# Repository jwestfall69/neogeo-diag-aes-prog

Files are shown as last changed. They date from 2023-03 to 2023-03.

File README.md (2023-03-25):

# neogeo-diag-aes-prog

## Overview
This is a custom NeoGeo AES Prog board that is used in conjunction with the [NeoGeo Diag Bios](https://github.com/jwestfall69/neogeo-diag-bios) that allows for testing the P ROM address and data buses between the motherboard and the cart slot.  Its meant to help trouble shoot getting a blue screen or if your game cart boots then crashes after a while (possible faulty P ROM bank switching).

It works by using an SRAM chip instead of a ROM for the program rom on the PROG board.  Doing this allows the diag bios to run tests on it similar to that of work ram to find issues.

Its not possible to test all lines related to the program rom, so there are 2 leds at the top of the board.  These 2 LEDs (ROMOE, PORTADDR) should be lit up when the P ROM Bus tests are running in the diag bios.

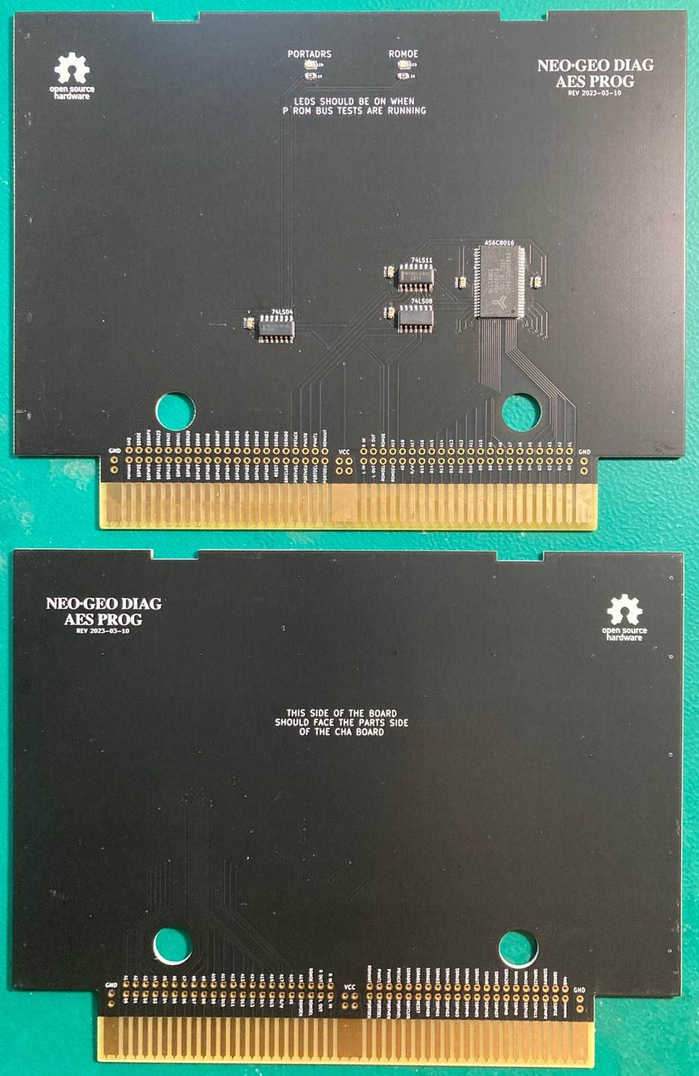
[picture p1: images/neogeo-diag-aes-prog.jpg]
neogeo-diag-aes-prog


## PCB Manufacturing
PCB should be 1.6mm thickness.  With these boards likely being inserted and removed numerous times its suggested you use ENIG surface finishing and gold fingers w/45 degree chamfering.

I've been using [jlcpcb](https://jlcpcb.com/) for PCB manufacturing.  Just watch out that by default they will add an order number to the silk screen unless you tell them not to.

## BOM
| Quantity | Description | Part Number | Digikey | Notes |
|:---:|:---|---|---|---|
| 1 | SRAM 8Mbit 44 pin TSOP II | AS6C8016-55ZIN | [1450-1041-ND](https://www.digikey.com/en/products/detail/alliance-memory-inc/AS6C8016-55ZIN/4234600) | |
| 1 | 74LS04 pin 14 SOIC | SN74LS04DR | [296-14875-2-ND](https://www.digikey.com/en/products/detail/texas-instruments/SN74LS04DR/562927) | |
| 1 | 74LS08 pin 14 SOIC | SN74LS08DR | [296-14879-2-ND](https://www.digikey.com/en/products/detail/texas-instruments/SN74LS08DR/562906) | |
| 1 | 74LS11 pin 14 SOIC | SN74LS11DR | [296-28984-2-ND](https://www.digikey.com/en/products/detail/texas-instruments/SN74LS11DR/1571760) | |
| 5 | 100nf / 0.1uf Ceramic Capacitor 0805 Size | CL21B104KBCNNNC | [1276-1003-2-ND](https://www.digikey.com/en/products/detail/samsung-electro-mechanics/CL21B104KBCNNNC/3886661) | Any 100nf 0805 is fine |
| 2 | 1K Ohm resistor 0805 Size | ERJ-6GEYJ102V | [P1.0KACT-ND](https://www.digikey.com/en/products/detail/panasonic-electronic-components/ERJ-6GEYJ102V/83014) | Any 1K 0805 resistor is fine |
| 2 | Green LED 0805 12mcd | LTST-C171GKT | [160-1423-2-ND](https://www.digikey.com/en/products/detail/liteon/LTST-C171GKT/386793) | Other 0805 size LEDs should be fine |

## Assembly
The SRAM has a really fine pin pitch, so take your time.  Other then that nothing special.

## Usage
The prog board should be used along with a valid CHA board.  Ideally you probably want a full diag cart where the CHA board has the M1 diag rom and this PROG board.  The cart should be inserted into the slot and then boot the board with the diag bios. Goto the main menu screen.

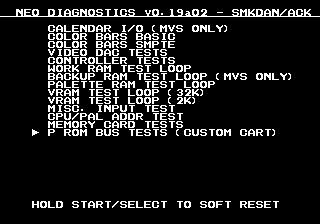
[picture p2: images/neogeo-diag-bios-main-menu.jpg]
main menu


Pick: ```P ROM BUS TESTS (CUSTOM CART)```

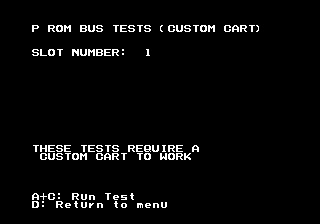
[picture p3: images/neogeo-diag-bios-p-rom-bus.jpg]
p rom bus tests


Since this is an AES you won't be able to change the slot number, so either press A+C to start the tests or D to go back to the main menu.

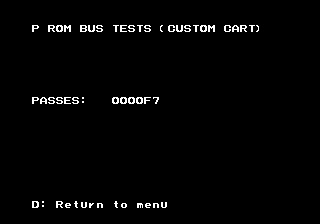
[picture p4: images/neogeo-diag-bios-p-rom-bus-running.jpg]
p rom bus tests running


The tests will run continually until D is pressed or an issue is detected.  While the tests are running you should expect the 2 LEDs on the PROG board to be lit up.

If you attempt to run the P rom bus tests without the diag PROG board you will get a ```P2 UNWRITABLE (LOWER)``` error.

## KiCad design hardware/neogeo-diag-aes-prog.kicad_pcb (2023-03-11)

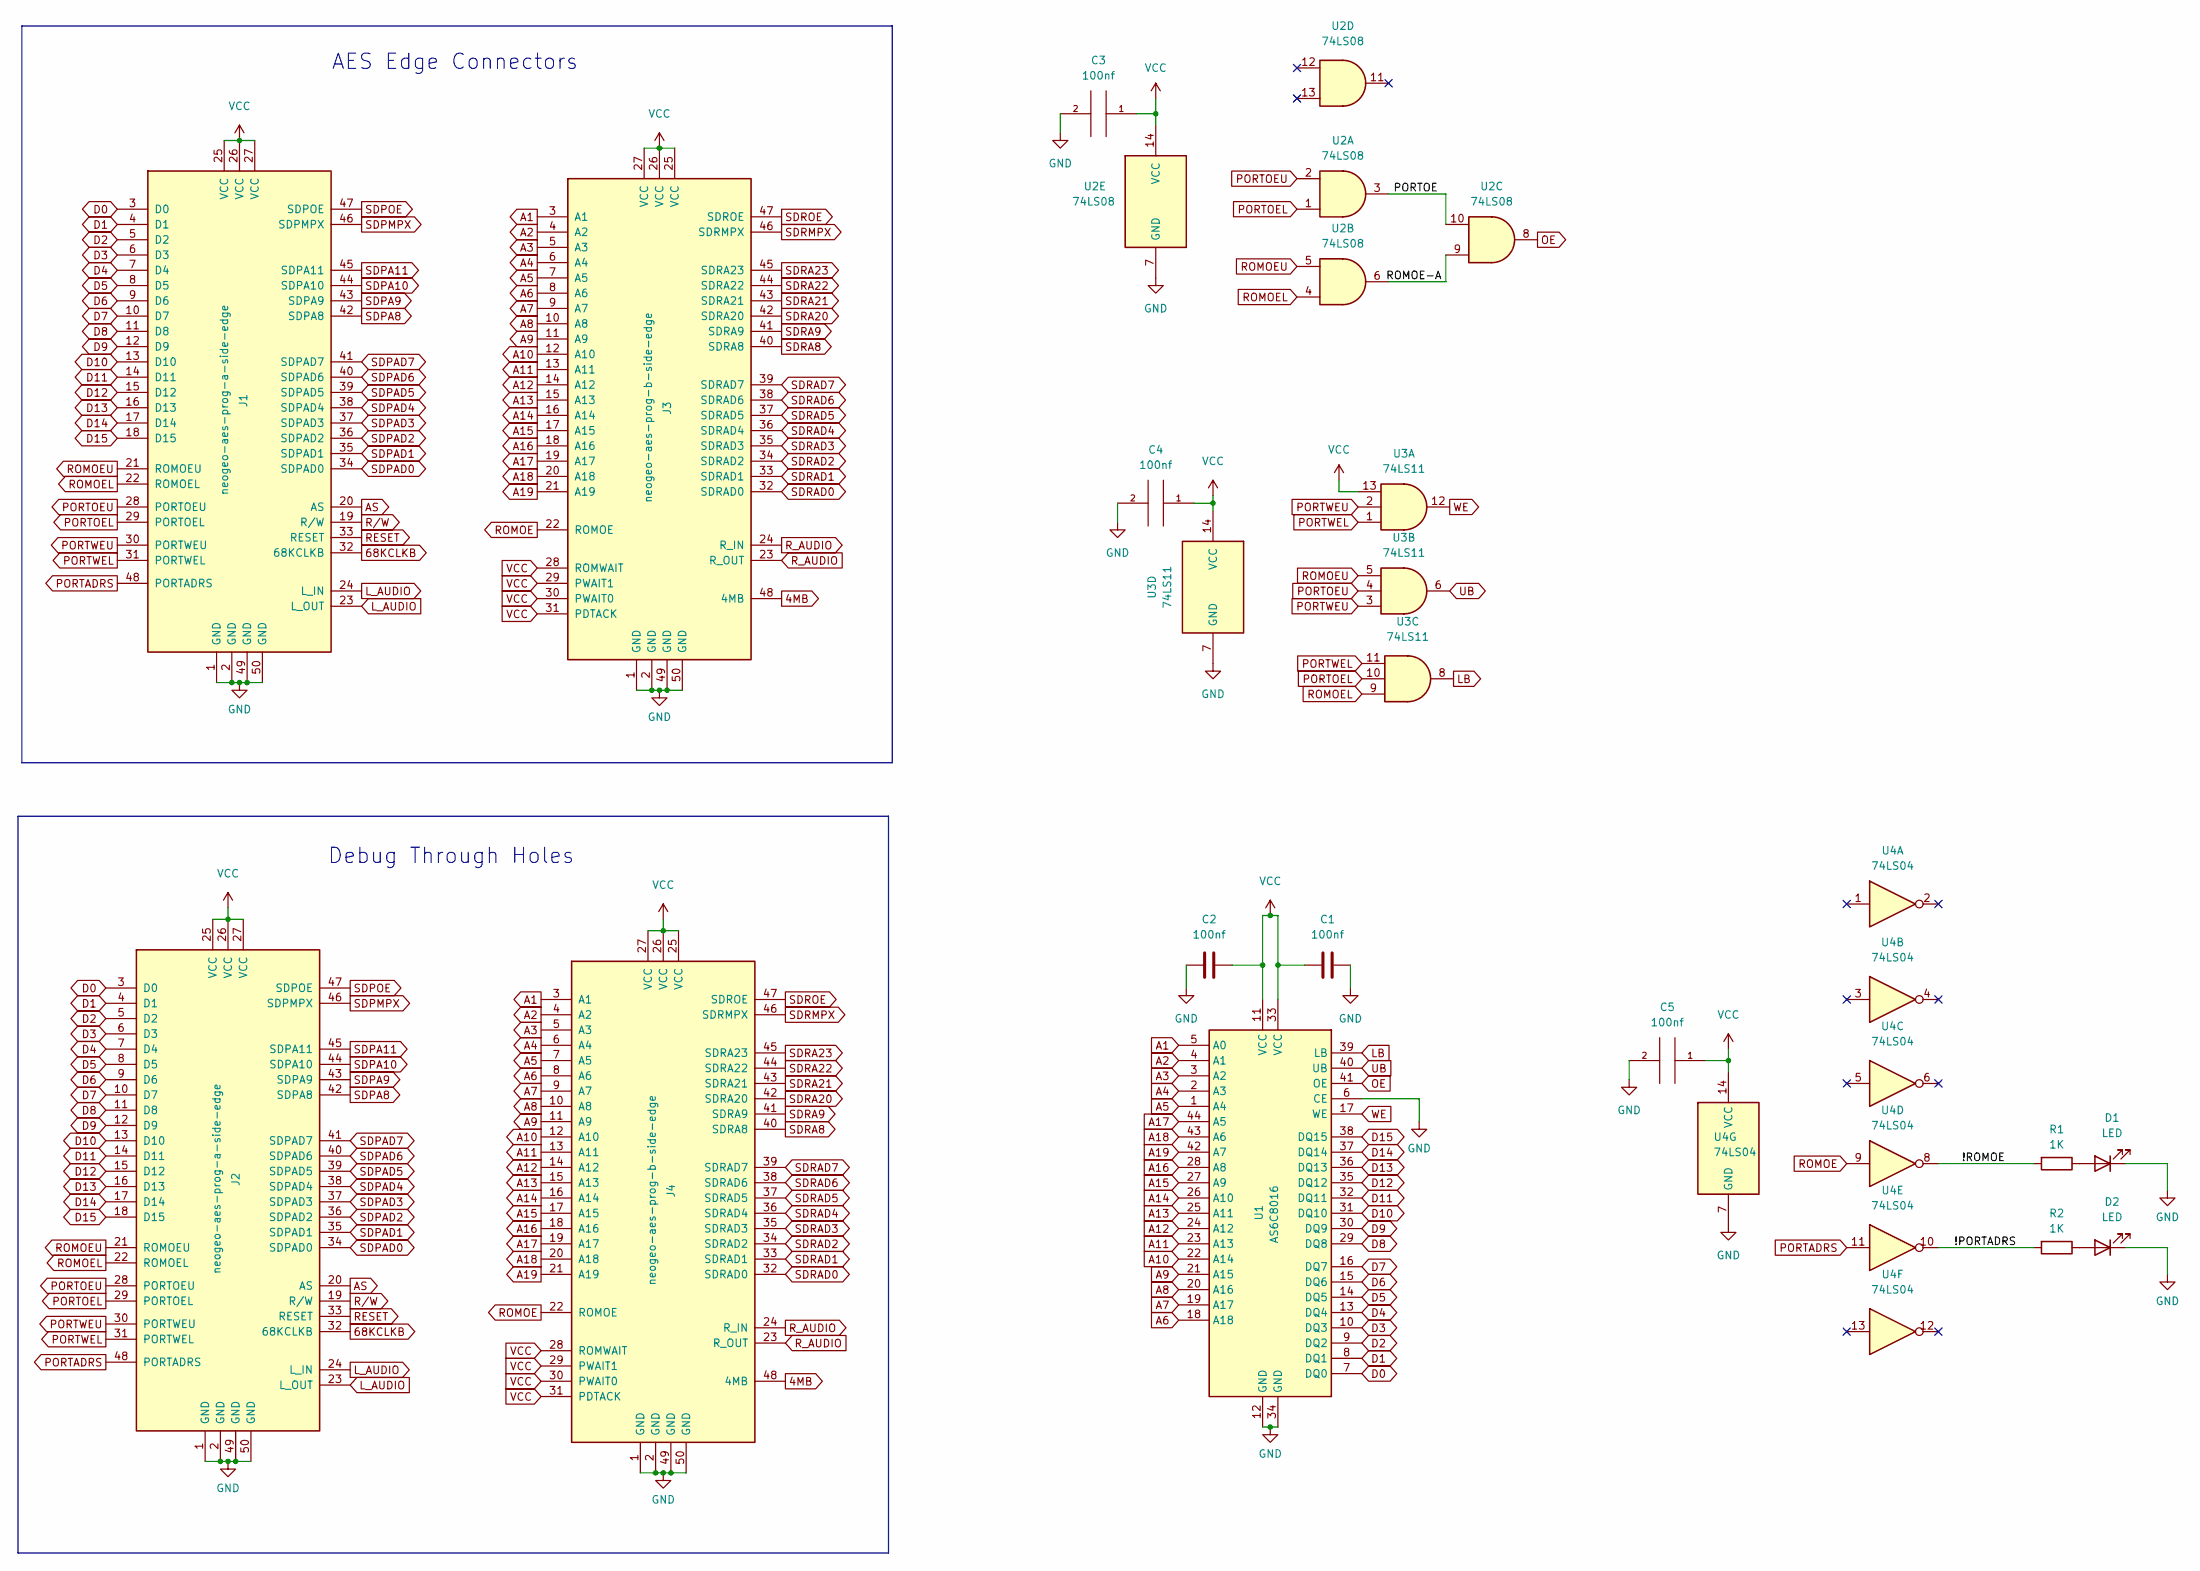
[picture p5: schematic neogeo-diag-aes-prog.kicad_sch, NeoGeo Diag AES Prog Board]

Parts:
C1, C2, C3, C4, C5: 100nf; C_0805_2012Metric
D1, D2: LED; LED_0805_2012Metric
J1: neogeo-aes-prog-a-side-edge
J2: neogeo-aes-prog-a-side-edge; neogeo-aes-prog-edge-test-points
J3: neogeo-aes-prog-b-side-edge
J4: neogeo-aes-prog-b-side-edge; neogeo-aes-prog-edge-test-points
R1, R2: 1K; R_0805_2012Metric
U1: AS6C8016; TSOP-II-44_10.16x18.41mm_P0.8mm
U2: 74LS08; SO-14_3.9x8.65mm_P1.27mm
U3: 74LS11; SO-14_3.9x8.65mm_P1.27mm
U4: 74LS04; SO-14_3.9x8.65mm_P1.27mm

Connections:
4MB: J3.48 (4MB), J4.48 (4MB)
68KCLKB: J1.32 (68KCLKB), J2.32 (68KCLKB)
/!PORTADRS: R2.2, U4.10
/!ROMOE: R1.2, U4.8
/PORTOE: U2.3, U2.10
/ROMOE-A: U2.6, U2.9
A1: J3.3 (A1), J4.3 (A1), U1.5 (A0)
A2: J3.4 (A2), J4.4 (A2), U1.4 (A1)
A3: J3.5 (A3), J4.5 (A3), U1.3 (A2)
A4: J3.6 (A4), J4.6 (A4), U1.2 (A3)
A5: J3.7 (A5), J4.7 (A5), U1.1 (A4)
A6: J3.8 (A6), J4.8 (A6), U1.18 (A18)
A7: J3.9 (A7), J4.9 (A7), U1.19 (A17)
A8: J3.10 (A8), J4.10 (A8), U1.20 (A16)
A9: J3.11 (A9), J4.11 (A9), U1.21 (A15)
A10: J3.12 (A10), J4.12 (A10), U1.22 (A14)
A11: J3.13 (A11), J4.13 (A11), U1.23 (A13)
A12: J3.14 (A12), J4.14 (A12), U1.24 (A12)
A13: J3.15 (A13), J4.15 (A13), U1.25 (A11)
A14: J3.16 (A14), J4.16 (A14), U1.26 (A10)
A15: J3.17 (A15), J4.17 (A15), U1.27 (A9)
A16: J3.18 (A16), J4.18 (A16), U1.28 (A8)
A17: J3.19 (A17), J4.19 (A17), U1.44 (A5)
A18: J3.20 (A18), J4.20 (A18), U1.43 (A6)
A19: J3.21 (A19), J4.21 (A19), U1.42 (A7)
AS: J1.20 (AS), J2.20 (AS)
D0: J1.3 (D0), J2.3 (D0), U1.7 (DQ0)
D1: J1.4 (D1), J2.4 (D1), U1.8 (DQ1)
D2: J1.5 (D2), J2.5 (D2), U1.9 (DQ2)
D3: J1.6 (D3), J2.6 (D3), U1.10 (DQ3)
D4: J1.7 (D4), J2.7 (D4), U1.13 (DQ4)
D5: J1.8 (D5), J2.8 (D5), U1.14 (DQ5)
D6: J1.9 (D6), J2.9 (D6), U1.15 (DQ6)
D7: J1.10 (D7), J2.10 (D7), U1.16 (DQ7)
D8: J1.11 (D8), J2.11 (D8), U1.29 (DQ8)
D9: J1.12 (D9), J2.12 (D9), U1.30 (DQ9)
D10: J1.13 (D10), J2.13 (D10), U1.31 (DQ10)
D11: J1.14 (D11), J2.14 (D11), U1.32 (DQ11)
D12: J1.15 (D12), J2.15 (D12), U1.35 (DQ12)
D13: J1.16 (D13), J2.16 (D13), U1.36 (DQ13)
D14: J1.17 (D14), J2.17 (D14), U1.37 (DQ14)
D15: J1.18 (D15), J2.18 (D15), U1.38 (DQ15)
GND: C1.1, C2.2, C3.2, C4.2, C5.2, D1.1 (K), D2.1 (K), J1.1 (GND), J1.2 (GND), J1.49 (GND), J1.50 (GND), J2.1 (GND), J2.2 (GND), J2.49 (GND), J2.50 (GND), J3.1 (GND), J3.2 (GND), J3.49 (GND), J3.50 (GND), J4.1 (GND), J4.2 (GND), J4.49 (GND), J4.50 (GND), U1.6 (CE), U1.12 (GND), U1.34 (GND), U2.7 (GND), U3.7 (GND), U4.7 (GND)
LB: U1.39 (LB), U3.8
L_AUDIO: J1.23 (L_OUT), J1.24 (L_IN), J2.23 (L_OUT), J2.24 (L_IN)
unnamed: D1.2 (A), R1.1
unnamed: D2.2 (A), R2.1
OE: U1.41 (OE), U2.8
PORTADRS: J1.48 (PORTADRS), J2.48 (PORTADRS), U4.11
PORTOEL: J1.29 (PORTOEL), J2.29 (PORTOEL), U2.1, U3.10
PORTOEU: J1.28 (PORTOEU), J2.28 (PORTOEU), U2.2, U3.4
PORTWEL: J1.31 (PORTWEL), J2.31 (PORTWEL), U3.1, U3.11
PORTWEU: J1.30 (PORTWEU), J2.30 (PORTWEU), U3.2, U3.3
RESET: J1.33 (RESET), J2.33 (RESET)
ROMOE: J3.22 (ROMOE), J4.22 (ROMOE), U4.9
ROMOEL: J1.22 (ROMOEL), J2.22 (ROMOEL), U2.4, U3.9
ROMOEU: J1.21 (ROMOEU), J2.21 (ROMOEU), U2.5, U3.5
R_AUDIO: J3.23 (R_OUT), J3.24 (R_IN), J4.23 (R_OUT), J4.24 (R_IN)
R/W: J1.19 (R/W), J2.19 (R/W)
SDPA8: J1.42 (SDPA8), J2.42 (SDPA8)
SDPA9: J1.43 (SDPA9), J2.43 (SDPA9)
SDPA10: J1.44 (SDPA10), J2.44 (SDPA10)
SDPA11: J1.45 (SDPA11), J2.45 (SDPA11)
SDPAD0: J1.34 (SDPAD0), J2.34 (SDPAD0)
SDPAD1: J1.35 (SDPAD1), J2.35 (SDPAD1)
SDPAD2: J1.36 (SDPAD2), J2.36 (SDPAD2)
SDPAD3: J1.37 (SDPAD3), J2.37 (SDPAD3)
SDPAD4: J1.38 (SDPAD4), J2.38 (SDPAD4)
SDPAD5: J1.39 (SDPAD5), J2.39 (SDPAD5)
SDPAD6: J1.40 (SDPAD6), J2.40 (SDPAD6)
SDPAD7: J1.41 (SDPAD7), J2.41 (SDPAD7)
SDPMPX: J1.46 (SDPMPX), J2.46 (SDPMPX)
SDPOE: J1.47 (SDPOE), J2.47 (SDPOE)
SDRA8: J3.40 (SDRA8), J4.40 (SDRA8)
SDRA9: J3.41 (SDRA9), J4.41 (SDRA9)
SDRA20: J3.42 (SDRA20), J4.42 (SDRA20)
SDRA21: J3.43 (SDRA21), J4.43 (SDRA21)
SDRA22: J3.44 (SDRA22), J4.44 (SDRA22)
SDRA23: J3.45 (SDRA23), J4.45 (SDRA23)
SDRAD0: J3.32 (SDRAD0), J4.32 (SDRAD0)
SDRAD1: J3.33 (SDRAD1), J4.33 (SDRAD1)
SDRAD2: J3.34 (SDRAD2), J4.34 (SDRAD2)
SDRAD3: J3.35 (SDRAD3), J4.35 (SDRAD3)
SDRAD4: J3.36 (SDRAD4), J4.36 (SDRAD4)
SDRAD5: J3.37 (SDRAD5), J4.37 (SDRAD5)
SDRAD6: J3.38 (SDRAD6), J4.38 (SDRAD6)
SDRAD7: J3.39 (SDRAD7), J4.39 (SDRAD7)
SDRMPX: J3.46 (SDRMPX), J4.46 (SDRMPX)
SDROE: J3.47 (SDROE), J4.47 (SDROE)
UB: U1.40 (UB), U3.6
VCC: C1.2, C2.1, C3.1, C4.1, C5.1, J1.25 (VCC), J1.26 (VCC), J1.27 (VCC), J2.25 (VCC), J2.26 (VCC), J2.27 (VCC), J3.25 (VCC), J3.26 (VCC), J3.27 (VCC), J3.28 (ROMWAIT), J3.29 (PWAIT1), J3.30 (PWAIT0), J3.31 (PDTACK), J4.25 (VCC), J4.26 (VCC), J4.27 (VCC), J4.28 (ROMWAIT), J4.29 (PWAIT1), J4.30 (PWAIT0), J4.31 (PDTACK), U1.11 (VCC), U1.33 (VCC), U2.14 (VCC), U3.13, U3.14 (VCC), U4.14 (VCC)
WE: U1.17 (WE), U3.12

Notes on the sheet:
Debug Through Holes
AES Edge Connectors

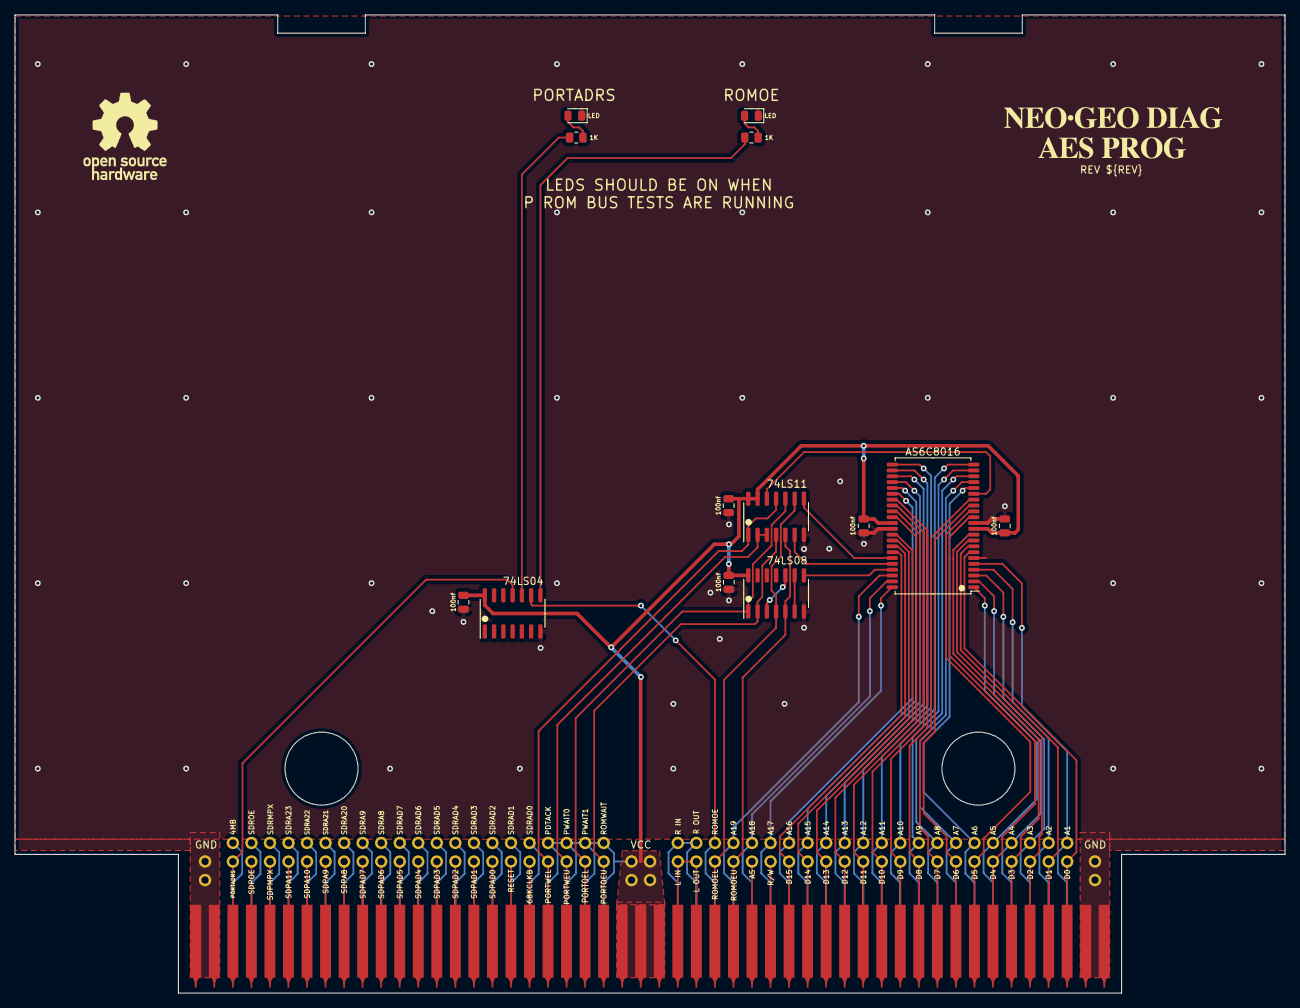
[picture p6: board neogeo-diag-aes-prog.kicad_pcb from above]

Board: 2 copper layers, 174.0 x 134.0 mm, 17 parts (1 on the bottom side), 92 nets.

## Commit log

2023-02-26 Pull updated kicad library
2023-03-07 Initial schematic/pcb
    [neogeo-diag-aes-prog.kicad_pcb, neogeo-diag-aes-prog.kicad_sch]
2023-03-07 Fix silkscreen typo 68KCLB -> 68KCLKB
    [neogeo-diag-aes-prog.kicad_pcb]
2023-03-11 Pull in newer neogeo-diag-kicad-library
2023-03-11 Add logo
    [neogeo-diag-aes-prog.kicad_pcb]
2023-03-11 Set output dir
    [neogeo-diag-aes-prog.kicad_pcb]
